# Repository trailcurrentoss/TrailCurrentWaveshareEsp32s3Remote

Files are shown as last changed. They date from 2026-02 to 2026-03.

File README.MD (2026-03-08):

# TrailCurrent Spotter

Touchscreen remote monitor for the [TrailCurrent](https://trailcurrent.com) modular vehicle system, built on the Waveshare ESP32-S3 4.3" touch display with LVGL GUI. Connects directly to the local MQTT broker over WiFi for real-time data and control.

## Hardware Overview

- **Display:** [Waveshare ESP32-S3 4.3" capacitive touchscreen](https://www.waveshare.com/product/arduino/boards-kits/esp32-s3/esp32-s3-touch-lcd-4.3.htm?aff_id=Trailcurrent) (800x480 RGB) — small form factor ideal for in-car usage where space is limited, and the ESP32-S3 provides more than sufficient performance for displaying real-time status alerts and alarms while driving
- **Microcontroller:** ESP32-S3 with 8MB flash, PSRAM (QIO OPI)
- **IO Expander:** CH422G I2C IO expander for display control
- **SD Card:** MicroSD slot (SPI on GPIO 11/12/13, CS via CH422G IO expander)
- **Communication:** WiFi — connects directly to the local Mosquitto MQTT broker (TLS on port 8883)
- **Key Features:**
  - Multi-page touch interface with bottom navigation bar
  - Real-time vehicle status via MQTT subscriptions
  - Light and accessory control via MQTT publish
  - SD card configuration — no on-screen credential entry needed
  - Configurable themes and screen timeout
  - Timezone-aware date/time display
  - User settings persisted in NVS (non-volatile storage)
  - 3D-printable enclosure with battery compartment

## GUI Pages

| Page | Function |
|---|---|
| **Home** | Status dashboard with warning indicators (lights, water, power, doors, cabinets, stabilizers) |
| **Trailer** | Trailer-specific monitoring and controls |
| **Power** | Battery voltage, state of charge, shore power status, PDM device control |
| **Solar** | Solar charge controller status and wattage |
| **Air** | Temperature (F), humidity, and air quality readings |
| **Settings** | Display theme, screen timeout, gateway MAC address, timezone, connectivity, about/version |

The GUI is designed with [EEZ Studio](https://www.envox.hr/eez/studio/studio-introduction.html) and rendered using LVGL 8.4.0.

## Device Configuration

Configuration is loaded from a `config.env` file and optional `ca.crt` on a MicroSD card. This avoids typing long credentials on the small touch keyboard.

**Setup steps:**

1. Create a file called `config.env` on a MicroSD card (FAT32 formatted)
2. Add your configuration values:

```
WIFI_SSID=YourNetworkName
WIFI_PWD=YourWiFiPassword
MQTT_HOST=192.168.1.100
MQTT_PORT=8883
MQTT_USER=mqttuser
MQTT_PASS=mqttpassword
```

3. Optionally copy the Mosquitto CA certificate as `ca.crt` to the SD card root for TLS server verification
4. Insert the SD card into the device and power on (or restart)
5. The device reads the config and CA cert, saves both to NVS, and connects automatically
6. The SD card can be removed after the first boot — settings persist in NVS

**Notes:**
- `MQTT_HOST` should be an IP address (ESP32 does not resolve `.local` mDNS hostnames)
- `MQTT_PORT` defaults to 8883 if omitted
- TLS encryption is always used; if no `ca.crt` is provided, certificate verification is skipped but the connection remains encrypted
- If no configuration exists (no SD card and no saved NVS values), the device shows "Configuration Required — Insert SD card with config.env and ca.crt then restart"
- Re-inserting an SD card will clear all previous connection settings and replace them with the new values on next boot

## Communication Protocol

The remote connects directly to the Mosquitto MQTT broker over TLS (port 8883). No intermediate server is required for real-time operation.

**Subscribe (status updates from CAN bus devices via MQTT):**

| Topic | Data Fields |
|---|---|
| `local/lights/+/status` | `state` (0/1), `brightness` (0-255) |
| `local/energy/status` | `battery_percent`, `battery_voltage`, `solar_watts`, `charge_type` |
| `local/airquality/temphumid` | `temperature` (Celsius — converted to F on device), `humidity` |
| `local/gps/latlon` | `latitude`, `longitude` |
| `local/gps/alt` | `altitudeFeet` |
| `local/gps/details` | `numberOfSatellites`, `speedOverGround`, `courseOverGround`, `gnssMode` |

**Publish (commands to devices):**

| Topic | Payload |
|---|---|
| `local/lights/{id}/command` | `{"state": 0\|1}` |

The MQTT client uses the ESP-IDF native `esp_mqtt_client` for event-driven, non-blocking message delivery.

## Firmware Setup

**Prerequisites:**
- [PlatformIO](https://platformio.org/) (CLI or IDE plugin)

**Build and upload:**
```bash
# Build firmware
pio run

# Upload to board (serial)
pio run -t upload
```

No secrets files are needed in the source. Device configuration (WiFi credentials, MQTT broker details) is loaded at runtime from an SD card — see [Device Configuration](#device-configuration) above.

## Case Design

A 3D-printable enclosure is included in the `CAD/` directory (FreeCAD format). The case accommodates a battery and physical buttons alongside the built-in touch interface.

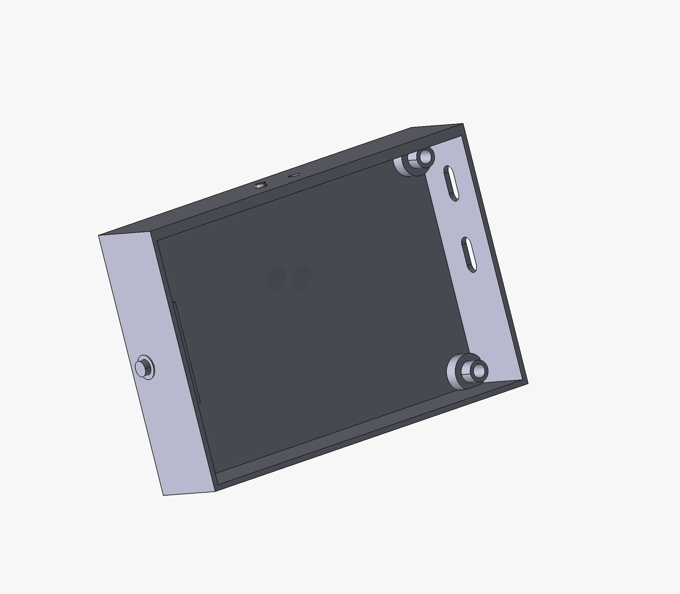
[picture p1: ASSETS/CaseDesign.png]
Case Design


## Project Structure

```
├── ASSETS/                       # Images and documentation assets
│   └── CaseDesign.png
├── CAD/                          # 3D-printable enclosure (FreeCAD)
│   └── TrailCurrentSpotter.FCStd
├── GUI/                          # EEZ Studio GUI project
│   └── TrailCurrentSpotter.eez-project
├── src/                          # Firmware source
│   ├── main.cpp                  # Application entry, LVGL setup, IO expander init, boot flow
│   ├── globals.h                 # Version, debug macros
│   ├── sdConfig.h / sdConfig.cpp # SD card config.env and ca.crt reader
│   ├── wifiHelper.h / .cpp       # WiFi connection management
│   ├── mqttClient.h / .cpp       # MQTT client (ESP-IDF native, TLS, pub/sub)
│   ├── actions.cpp               # UI event handlers (navigation, settings, themes, controls)
│   ├── vars.cpp                  # State variables, LVGL widget updates, time conversion
│   └── ui/                       # Generated LVGL UI code (from EEZ Studio — do not edit)
│       ├── screens.h / screens.c # Screen and widget object definitions
│       ├── styles.h / styles.c   # Theme styles
│       ├── vars.h                # Variable getter/setter declarations
│       ├── actions.h             # Action function declarations
│       ├── images.h / images.c   # Embedded images
│       └── fonts/                # Custom fonts (FontAwesome icons)
├── lib/                          # Local libraries
│   └── ESP32_Display_Panel/      # Waveshare display driver (ESP-IDF based)
├── 8MB_no_ota.csv                # Flash partition table
└── platformio.ini                # Build configuration
```

## Dependencies

| Library | Source | Purpose |
|---|---|---|
| LVGL 8.4.0 | PlatformIO registry | GUI framework |
| ArduinoJson 7.x | PlatformIO registry | JSON parsing for MQTT messages |
| ESP-IDF MQTT | Built-in (ESP-IDF) | Native MQTT client with TLS support |
| ESP32_Display_Panel | Local (`lib/`) | Waveshare display and touch driver |
| SD / SPI | ESP32 Arduino built-in | SD card access for config.env and ca.crt |
| WiFi | ESP32 Arduino built-in | WiFi connectivity |

## License

MIT License - See LICENSE file for details.

This is open source hardware and software. You are free to use, modify, and distribute under the terms of the MIT license.

## Contributing

Improvements and contributions are welcome! Please submit issues or pull requests.

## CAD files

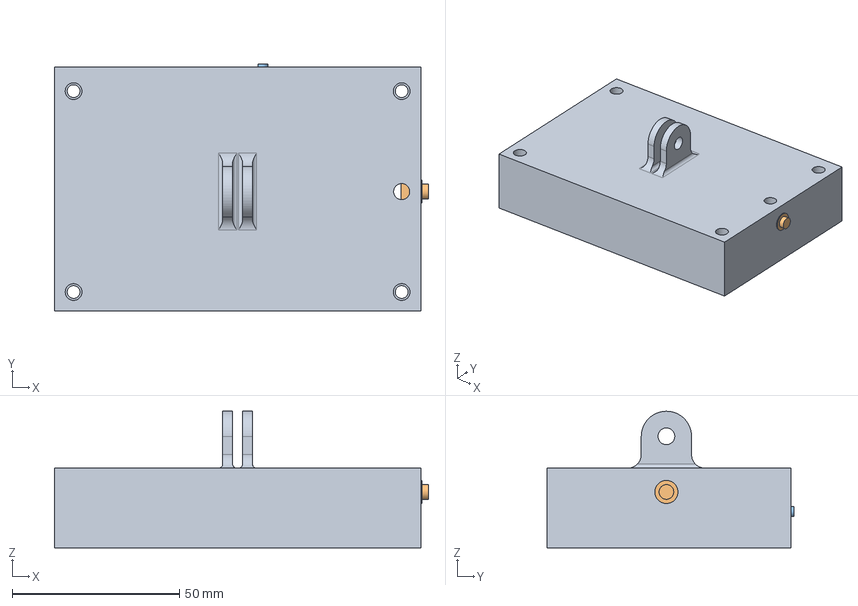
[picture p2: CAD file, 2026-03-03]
CAD/TrailCurrentSpotter.FCStd
111.7 x 73.8 x 40.8 mm
BodyWaveshare43Case
BodyOnOffButton
BodyButtons

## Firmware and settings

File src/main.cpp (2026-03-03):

#include <Arduino.h>
#include "globals.h"
#include <lvgl.h>
#include <ESP_Panel_Library.h>
#include <ESP_IOExpander_Library.h>
#include "ui/ui.h"
#include "ui/vars.h"
#include "wifiHelper.h"
#include "mqttClient.h"
#include "sdConfig.h"
#include <Preferences.h>
Preferences preferences; // NVS storage for user settings
extern void setup_wifi_keyboard();
extern void setup_server_config_keyboard();
extern void prepare_server_config_screen();
extern void setup_light_buttons();
static ESP_IOExpander *expander = NULL;
unsigned long int previousuStatusCheckMillis = 0;
long uStatusCheckInterval = 33;

// Extend IO Pin define
#define TP_RST 1
#define LCD_BL 2
#define LCD_RST 3
#define SD_CS 4
#define USB_SEL 5

// I2C Pin define
#define I2C_MASTER_NUM 0
#define I2C_MASTER_SDA_IO 8
#define I2C_MASTER_SCL_IO 9

/* LVGL porting configurations */
#define LVGL_TICK_PERIOD_MS (2)
#define LVGL_TASK_MAX_DELAY_MS (500)
#define LVGL_TASK_MIN_DELAY_MS (1)
#define LVGL_TASK_STACK_SIZE (4 * 1024)
#define LVGL_TASK_PRIORITY (2)
#define LVGL_BUF_SIZE (ESP_PANEL_LCD_H_RES * 50)

ESP_Panel *panel = NULL;
SemaphoreHandle_t lvgl_mux = NULL; // LVGL mutex

#if ESP_PANEL_LCD_BUS_TYPE == ESP_PANEL_BUS_TYPE_RGB
/* Display flushing */
void lvgl_port_disp_flush(lv_disp_drv_t *disp, const lv_area_t *area, lv_color_t *color_p)
{
    panel->getLcd()->drawBitmap(area->x1, area->y1, area->x2 + 1, area->y2 + 1, color_p);
    lv_disp_flush_ready(disp);
}
#else
/* Display flushing */
void lvgl_port_disp_flush(lv_disp_drv_t *disp, const lv_area_t *area, lv_color_t *color_p)
{
    panel->getLcd()->drawBitmap(area->x1, area->y1, area->x2 + 1, area->y2 + 1, color_p);
}

bool notify_lvgl_flush_ready(void *user_ctx)
{
    lv_disp_drv_t *disp_driver = (lv_disp_drv_t *)user_ctx;
    lv_disp_flush_ready(disp_driver);
    return false;
}
#endif /* ESP_PANEL_LCD_BUS_TYPE */

#if ESP_PANEL_USE_LCD_TOUCH
/* Read the touchpad */
void lvgl_port_tp_read(lv_indev_drv_t *indev, lv_indev_data_t *data)
{
    panel->getLcdTouch()->readData();

    bool touched = panel->getLcdTouch()->getTouchState();
    if (!touched)
    {
        data->state = LV_INDEV_STATE_REL;
    }
    else
    {
        TouchPoint point = panel->getLcdTouch()->getPoint();

        data->state = LV_INDEV_STATE_PR;
        /*Set the coordinates*/
        data->point.x = point.x;
        data->point.y = point.y;
    }
}
#endif

void lvgl_port_lock(int timeout_ms)
{
    const TickType_t timeout_ticks = (timeout_ms < 0) ? portMAX_DELAY : pdMS_TO_TICKS(timeout_ms);
    xSemaphoreTakeRecursive(lvgl_mux, timeout_ticks);
}

void lvgl_port_unlock(void)
{
    xSemaphoreGiveRecursive(lvgl_mux);
}

void lvgl_port_task(void *arg)
{
    debugln("Starting LVGL task");

    uint32_t task_delay_ms = LVGL_TASK_MAX_DELAY_MS;
    while (1)
    {
        // Lock the mutex due to the LVGL APIs are not thread-safe
        lvgl_port_lock(-1);
        task_delay_ms = lv_timer_handler();
        // Release the mutex
        lvgl_port_unlock();
        if (task_delay_ms > LVGL_TASK_MAX_DELAY_MS)
        {
            task_delay_ms = LVGL_TASK_MAX_DELAY_MS;
        }
        else if (task_delay_ms < LVGL_TASK_MIN_DELAY_MS)
        {
            task_delay_ms = LVGL_TASK_MIN_DELAY_MS;
        }
        vTaskDelay(pdMS_TO_TICKS(task_delay_ms));
    }
}

void setup()
{
    Serial.begin(115200);  /* USB CDC debug output */
    Serial0.begin(115200); /* UART0 debug output */

    String LVGL_Arduino = "Hello LVGL! ";
    LVGL_Arduino += String('V') + lv_version_major() + "." + lv_version_minor() + "." + lv_version_patch();

    debugln(LVGL_Arduino);
    debugln("I am ESP32_Display_Panel");

    panel = new ESP_Panel();

    /* Initialize LVGL core */
    lv_init();

    /* Initialize LVGL buffers */
    static lv_disp_draw_buf_t draw_buf;
    /* Using double buffers is more faster than single buffer */
    /* Use PSRAM for display buffers to leave internal SRAM available for WiFi */
    uint8_t *buf = (uint8_t *)heap_caps_calloc(1, LVGL_BUF_SIZE * sizeof(lv_color_t), MALLOC_CAP_SPIRAM);
    uint8_t *buf2 = (uint8_t *)heap_caps_calloc(1, LVGL_BUF_SIZE * sizeof(lv_color_t), MALLOC_CAP_SPIRAM);
    assert(buf);
    lv_disp_draw_buf_init(&draw_buf, buf, buf2, LVGL_BUF_SIZE);

    /* Initialize the display device */
    static lv_disp_drv_t disp_drv;
    lv_disp_drv_init(&disp_drv);
    /* Change the following line to your display resolution */
    disp_drv.hor_res = ESP_PANEL_LCD_H_RES;
    disp_drv.ver_res = ESP_PANEL_LCD_V_RES;
    disp_drv.flush_cb = lvgl_port_disp_flush;
    disp_drv.draw_buf = &draw_buf;
    lv_disp_drv_register(&disp_drv);

#if ESP_PANEL_USE_LCD_TOUCH
    /* Initialize the input device */
    static lv_indev_drv_t indev_drv;
    lv_indev_drv_init(&indev_drv);
    indev_drv.type = LV_INDEV_TYPE_POINTER;
    indev_drv.read_cb = lvgl_port_tp_read;
    lv_indev_drv_register(&indev_drv);
#endif
    /* Initialize bus and device of panel */
    panel->init();
#if ESP_PANEL_LCD_BUS_TYPE != ESP_PANEL_BUS_TYPE_RGB
    /* Register a function to notify LVGL when the panel is ready to flush */
    /* This is useful for refreshing the screen using DMA transfers */
    panel->getLcd()->setCallback(notify_lvgl_flush_ready, &disp_drv);
#endif

    debugln("Initialize IO expander");
    /* Initialize IO expander */
    expander = new ESP_IOExpander_CH422G(I2C_MASTER_NUM, ESP_IO_EXPANDER_I2C_CH422G_ADDRESS_000);
    expander->init();
    expander->begin();
    expander->multiPinMode(TP_RST | LCD_BL | LCD_RST | SD_CS | USB_SEL, OUTPUT);
    expander->multiDigitalWrite(TP_RST | LCD_BL | LCD_RST | SD_CS, HIGH);

    expander->digitalWrite(USB_SEL, LOW);
    /* Add into panel */
    panel->addIOExpander(expander);

    /* Start panel */
    panel->begin();

    /* Create a task to run the LVGL task periodically */
    lvgl_mux = xSemaphoreCreateRecursiveMutex();
    xTaskCreate(lvgl_port_task, "lvgl", LVGL_TASK_STACK_SIZE, NULL, LVGL_TASK_PRIORITY, NULL);

    /* Lock the mutex due to the LVGL APIs are not thread-safe */
    lvgl_port_lock(-1);

    ui_init();
    setup_light_buttons();

    /* Release the mutex */
    lvgl_port_unlock();

    // Initialize NVS preferences
    preferences.begin("user_settings", false);

    // Try reading config from SD card (writes values to NVS if found)
    sdConfig::readConfigFromSD(expander, preferences);

    // Initialize WiFi (picks up any fresh values from SD card)
    wifiHelper::initialize(preferences);

    // Load MQTT settings from NVS (picks up any fresh values from SD card)
    mqttClient::loadSettings(preferences);

    // Load saved UI settings from NVS
    int savedTheme = preferences.getInt("selectedTheme", 0);
    int screenTimeout = preferences.getInt("screenTimeout", 0);
    bool keepScreenOnWhileDriving = preferences.getBool("onWhileDriving", true);
    String savedTimezone = preferences.getString("timeZone", "ASKT9AKDT,M3.2.0/2:00:00,M11.1.0/2:00:00");
    set_var_selected_theme(savedTheme);
    set_var_screen_timeout_value(screenTimeout);
    set_var_keep_screen_on_while_driving(keepScreenOnWhileDriving);
    const char *timezoneItemsList[7] = {"ASKT9AKDT,M3.2.0/2:00:00,M11.1.0/2:00:00", "CST6CDT,M3.2.0/2:00:00,M11.1.0/2:00:00", "MST7MDT,M3.2.0/2:00:00,M11.1.0/2:00:00", "HST11HDT,M3.2.0/2:00:00,M11.1.0/2:00:00", "PST8PDT,M3.2.0/2:00:00,M11.1.0/2:00:00", "EST5EDT,M3.2.0/2:00:00,M11.1.0/2:00:00", "MST7"};
    int selectedTimezone = 0;
    savedTimezone.trim();
    const char *savedTimezoneChar = savedTimezone.c_str();
    for (int i = 0; i < 7; i++)
    {
        if (strcmp(timezoneItemsList[i], savedTimezoneChar) == 0)
        {
            debugln("Found selected timezone");
            debugf("[Settings] Timezone: %s\n", timezoneItemsList[i]);
            selectedTimezone = i;
        }
    }
    lv_dropdown_set_selected(objects.drop_down_selected_time_zone, selectedTimezone);
    set_var_current_time_zone_string(savedTimezoneChar);
    // Set the version number label
    lv_label_set_text(objects.label_version_number, CURRENT_VERSION);

    // Determine which screen to show on boot
    if (!wifiHelper::hasCredentials() && !mqttClient::hasConfig())
    {
        // No config at all - show "insert SD card" message
        debugln("[Boot] No configuration found, showing SD card prompt");
        lv_scr_load(objects.wifi_setup);
        lv_obj_clear_flag(objects.wifi_setup, LV_OBJ_FLAG_SCROLLABLE);
        // Hide all interactive widgets - just show a message
        lv_obj_add_flag(objects.roller_wifi_networks, LV_OBJ_FLAG_HIDDEN);
        lv_obj_add_flag(objects.textarea_wifi_ssid, LV_OBJ_FLAG_HIDDEN);
        lv_obj_add_flag(objects.label_wifi_ssid, LV_OBJ_FLAG_HIDDEN);
        lv_obj_add_flag(objects.textarea_wifi_password, LV_OBJ_FLAG_HIDDEN);
        lv_obj_add_flag(objects.label_wifi_password, LV_OBJ_FLAG_HIDDEN);
        lv_obj_add_flag(objects.btn_wifi_connect, LV_OBJ_FLAG_HIDDEN);
        lv_obj_add_flag(objects.btn_wifi_skip, LV_OBJ_FLAG_HIDDEN);
        lv_obj_add_flag(objects.btn_wifi_scan, LV_OBJ_FLAG_HIDDEN);
        lv_label_set_text(objects.label_wifi_setup_title, "Configuration Required");
        set_var_connection_status_text("Insert SD card with config.env and ca.crt then restart");
    }
    else if (wifiHelper::isConnected() && mqttClient::hasConfig())
    {
        // Everything configured and WiFi connected - connect MQTT
        debugln("[Boot] Fully configured, connecting MQTT");
        mqttClient::connect();
    }
    else
    {
        debugln("[Boot] Partial config - waiting for WiFi or reconnect");
    }

    debugln("Setup done");
}

void loop()
{
    // Process queued MQTT messages (with LVGL mutex for thread safety)
    mqttClient::loop();

    // If settings have changed we need to persist them
    if (get_var_user_settings_changed())
    {
        int selectedTheme = get_var_selected_theme();
        int screenTimeout = get_var_screen_timeout_value();
        bool keepScreenOnWhileDriving = get_var_keep_screen_on_while_driving();
        preferences.putInt("selectedTheme", selectedTheme);
        preferences.putInt("screenTimeout", screenTimeout);
        preferences.putBool("onWhileDriving", keepScreenOnWhileDriving);
        preferences.putString("timeZone", get_var_current_time_zone_string());
        set_var_user_settings_changed(false);
    }

    // Check WiFi reconnection
    wifiHelper::checkReconnect();

    // If WiFi just connected and MQTT hasn't been started yet, connect
    if (wifiHelper::isConnected() && !mqttClient::isConnected() && mqttClient::hasConfig())
    {
        static unsigned long lastMqttConnectAttempt = 0;
        unsigned long now = millis();
        if (now - lastMqttConnectAttempt >= 5000)
        {
            lastMqttConnectAttempt = now;
            debugln("[Loop] WiFi connected, starting MQTT...");
            mqttClient::connect();
        }
    }

    unsigned long currentStatusCheckMillis = millis();
    if (currentStatusCheckMillis - previousuStatusCheckMillis >= uStatusCheckInterval)
    {
        lvgl_port_lock(-1);
        if ((get_var_pdm01_device01_status() > 0) || (get_var_pdm01_device02_status() > 0) || (get_var_pdm01_device03_status() > 0) || (get_var_pdm01_device04_status() > 0) || (get_var_pdm01_device05_status() > 0) || (get_var_pdm01_device08_status() > 0))
        {
            lv_obj_add_state(objects.label_warning_icon_lights, LV_STATE_CHECKED);
            lv_obj_add_state(objects.label_warning_text_lights, LV_STATE_CHECKED);
        }
        else
        {
            lv_obj_clear_state(objects.label_warning_icon_lights, LV_STATE_CHECKED);
            lv_obj_clear_state(objects.label_warning_text_lights, LV_STATE_CHECKED);
        }
        if (get_var_pdm01_device07_status() > 0)
        {
            lv_obj_add_state(objects.label_warning_icon_water, LV_STATE_CHECKED);
            lv_obj_add_state(objects.label_warning_text_water, LV_STATE_CHECKED);
        }
        else
        {
            lv_obj_clear_state(objects.label_warning_icon_water, LV_STATE_CHECKED);
            lv_obj_clear_state(objects.label_warning_text_water, LV_STATE_CHECKED);
        }
        lvgl_port_unlock();
        previousuStatusCheckMillis = currentStatusCheckMillis;
    }
    delay(5);
}

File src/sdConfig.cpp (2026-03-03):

#include "sdConfig.h"
#include "globals.h"
#include <SPI.h>
#include <SD.h>

// SD card SPI pins (Waveshare ESP32-S3-Touch-LCD-4.3)
#define SD_SPI_SCK 12
#define SD_SPI_MISO 13
#define SD_SPI_MOSI 11
#define SD_CS_EXPANDER_PIN 4

namespace sdConfig
{
    static bool parseLine(const String &line, String &key, String &value)
    {
        int eqIdx = line.indexOf('=');
        if (eqIdx <= 0)
            return false;

        key = line.substring(0, eqIdx);
        value = line.substring(eqIdx + 1);
        key.trim();
        value.trim();
        return key.length() > 0;
    }

    bool readConfigFromSD(ESP_IOExpander *expander, Preferences &prefs)
    {
        debugln("[SD] Attempting to read config from SD card...");

        // Pull CS LOW to select SD card
        expander->digitalWrite(SD_CS_EXPANDER_PIN, LOW);

        // Initialize SPI bus for SD card
        SPI.begin(SD_SPI_SCK, SD_SPI_MISO, SD_SPI_MOSI);

        // Mount SD card (CS is held LOW by expander, pass -1 as CS pin)
        if (!SD.begin(-1, SPI))
        {
            debugln("[SD] Failed to mount SD card");
            SPI.end();
            expander->digitalWrite(SD_CS_EXPANDER_PIN, HIGH);
            return false;
        }

        debugln("[SD] SD card mounted");

        // Open config file
        File configFile = SD.open("/config.env", FILE_READ);
        if (!configFile)
        {
            debugln("[SD] config.env not found");
            SD.end();
            SPI.end();
            expander->digitalWrite(SD_CS_EXPANDER_PIN, HIGH);
            return false;
        }

        debugln("[SD] Reading config.env...");

        // Clear all connection-related NVS keys so SD card is the single source of truth
        prefs.remove("wifiSSID");
        prefs.remove("wifiPass");
        prefs.remove("mqttHost");
        prefs.remove("mqttPort");
        prefs.remove("mqttUser");
        prefs.remove("mqttPass");
        prefs.remove("mqttCaCert");
        // Remove legacy keys from old firmware versions
        prefs.remove("serverUrl");
        prefs.remove("apiKey");
        debugln("[SD] Cleared old NVS connection settings");

        bool foundWifi = false;

        while (configFile.available())
        {
            String line = configFile.readStringUntil('\n');
            line.trim();

            // Skip empty lines and comments
            if (line.length() == 0 || line.startsWith("#"))
                continue;

            String key, value;
            if (!parseLine(line, key, value))
                continue;

            if (key == "WIFI_SSID" && value.length() > 0)
            {
                prefs.putString("wifiSSID", value.c_str());
                debugf("[SD] WiFi SSID: %s\n", value.c_str());
                foundWifi = true;
            }
            else if (key == "WIFI_PWD")
            {
                prefs.putString("wifiPass", value.c_str());
                debugln("[SD] WiFi password set");
            }
            else if (key == "MQTT_HOST" && value.length() > 0)
            {
                prefs.putString("mqttHost", value.c_str());
                debugf("[SD] MQTT Host: %s\n", value.c_str());
            }
            else if (key == "MQTT_PORT" && value.length() > 0)
            {
                int p = value.toInt();
                if (p > 0 && p <= 65535)
                {
                    prefs.putUShort("mqttPort", (uint16_t)p);
                    debugf("[SD] MQTT Port: %d\n", p);
                }
            }
            else if (key == "MQTT_USER" && value.length() > 0)
            {
                prefs.putString("mqttUser", value.c_str());
                debugf("[SD] MQTT User: %s\n", value.c_str());
            }
            else if (key == "MQTT_PASS" && value.length() > 0)
            {
                prefs.putString("mqttPass", value.c_str());
                debugln("[SD] MQTT password set");
            }
        }

        configFile.close();

        // Read CA certificate if present
        File certFile = SD.open("/ca.crt", FILE_READ);
        if (certFile)
        {
            String certPem = certFile.readString();
            certFile.close();
            if (certPem.length() > 0)
            {
                prefs.putString("mqttCaCert", certPem.c_str());
                debugf("[SD] CA cert stored (%d bytes)\n", certPem.length());
            }
        }
        else
        {
            debugln("[SD] ca.crt not found (optional)");
        }

        SD.end();
        SPI.end();
        expander->digitalWrite(SD_CS_EXPANDER_PIN, HIGH);

        debugf("[SD] Config read complete (WiFi found: %s)\n", foundWifi ? "yes" : "no");
        return foundWifi;
    }
}

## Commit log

2026-02-14 Starting project
    [8MB_no_ota.csv, TrailCurrentWaveshareEsp32s3Remote.FCStd]
2026-03-03 Switched to WiFi and MQTT for fast reliable communications
    [TrailCurrentWaveshareEsp32s3Remote.FCStd]
2026-03-08 Naming to align with product names
    [TrailCurrentSpotter.FCStd]
